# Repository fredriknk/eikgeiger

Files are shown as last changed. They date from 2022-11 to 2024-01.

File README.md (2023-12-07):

# EIKGEIGER
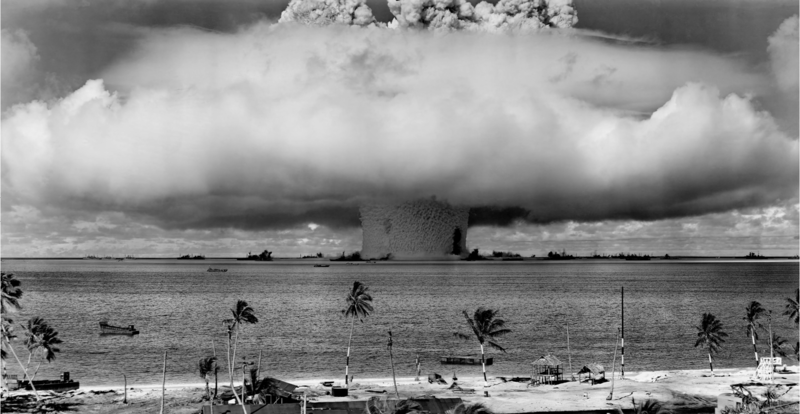
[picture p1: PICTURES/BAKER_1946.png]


Eikgeiger opensource project for detection of background radiation in Norway. It is developed in cooperation with Eik Ideverksted. Use the design for anything you like comercially and privately, but i would love if you fork it so i can see what it is used for.

## First Batch
Thanks to [PCBway](www.pcbway.com) for providing assembled prototype units for this project. Its awesome that you support the opensource community like this! If you want one for yourself, i've made a [pcbway project](https://www.pcbway.com/project/shareproject/EikGeiger_IOT_Geigercounter_60bd1e1f.html) which you can make an assembly order quite easily. 

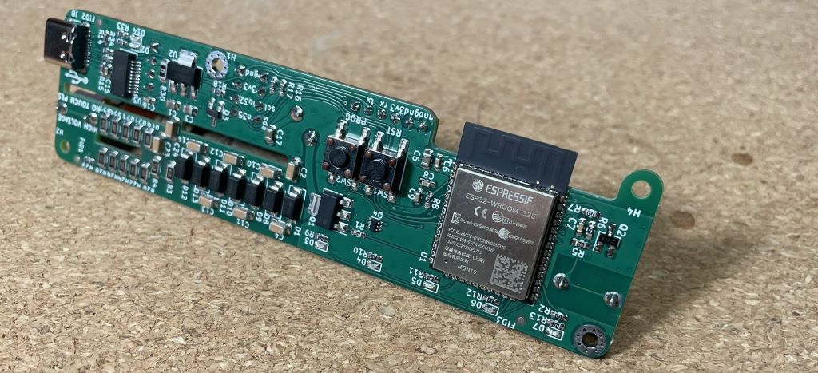
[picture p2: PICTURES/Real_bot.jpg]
REALBOT

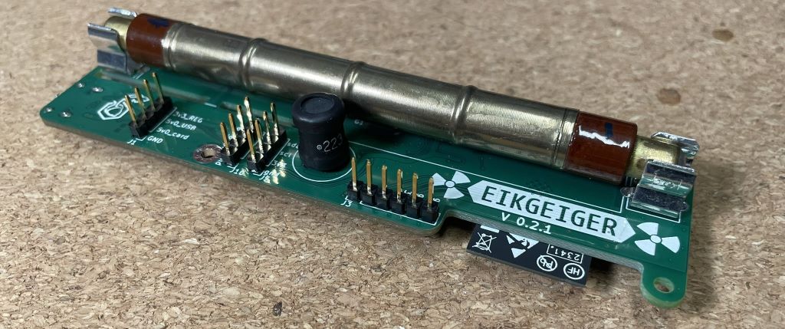
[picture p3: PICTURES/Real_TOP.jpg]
REALTOP


## Description
It uses an[ESP32-WROOM-32E](./DOCUMENTATION/esp32-wroom-32e_esp32-wroom-32ue_datasheet_en.pdf) wifi module both communication and MCU, and is mostly based on surface mount components.

Thanks to the DIYgeiger radmon project for inspiration [DIYGeiger RADMON + kit](https://sites.google.com/site/diygeigercounter/home/gk-radmon).

If you want to handsolder this, i really recommend to check out the awesome IBOM assembly utility (use it with a desktop as it sucks on mobile)
[Assembly IBOM](https://htmlpreview.github.io/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)

[SCHEMATIC](./DOCUMENTATION/Opengieger_schematic.pdf)
## Specifications
| **Parameter** | **Description** |
|---|---|
| _Input voltage_ | Usb-C cable, Header 4-6v, Direct 3.3v |
| _Current_ | Wifi: 150-250mA, Radio Off: 44mA, Only HV psup 4mA, Deep sleep 70uA |
| _Communication_ | 2.4ghz WIFI, Uart TTL, Uart over USB |
| _Baudrate_ | 115200 |
| _PCB size_ | 31x119mm |
| _Case size_ | 30x35x121mm |
| _Series Resistor_ | 4.51MOHM |

## Serial port controll comands

To reconfigure device settings you need to connect the eikgeiger to a computer with a serial terminal (I reccomend to just use the [Arduino Program](https://www.arduino.cc/en/software), but any serial terminal should work)

When you want to configure a value you use two characters plus a number. So to set the PWM frequency to 2000hz, you would write PF2000 in the terminal and send. Some commands need a specific number, eg to factory reset you must transmit FR9999. after you have verified that the configuraion works you use SA1 to save the config to the flash eeprom

| **Characters**| **Unit** | **Value** | **Factory Value** | **Description** | **Example** |
|---|---|---|---|---|---|
| VO | _VOLT (value/4096 %)_ | 0-2000 | 350 | Set pwm duty cycle, this is a value which controlls the duty cycle of HV power supply, it is a 12bit (4096) value, but you cant go over 50% or the coil field colapses. So keep it under 2046=50% duty cycle. (SBM-20 tubes like it best between 350-400) | VO350 |
| VF | _FREQUENCY (hz)_ | 0-18000 | 1001 | Set pwm frequency, from experimentation i have found ~1000hz to be most effective but it can make some coil whine, It is smart to not have this as a value divisible by log output, or it might generate some interferance with ADC readings | VF1001 |
| SA | _SAVE_ | 1 | - | Saves parameters to eeprom | SA1 |
| RE | _RESTART_ | 1 | - | Restarts device | RE1 |
| RF | _FACTORY RESET_ | 9999/1111 | - | Resets all values to factory default and restarts device, 1111 will reset all settings except wifi and radmon credentials, 9999 resets everything | RF9999 |
| BE | _BEEPER (activation)_ | 0/1 | 0 | Activate beeper output 0=Off 1=On | BE1 |
| BD | _BEEPER duty (val/255) _| 0-127 | 50 | Beeper duty cycle, higher number is louder | BD50 |
| BF | _BEEPER FREQUENCY (hz)_ | 10-40000  | 6000 | Beeper frequency 6000hZ is a very nice and annoying frequency | BF6000 |
| LE | _LED (activation)_ | 0/1 | 1 | Activate LED output 0=Off 1=On | LE1 |
| LF | _FLASHTIME (mS)_ | 1-500 | 10 | How long the beeper beeps and led flashes in mS for every click. If value is higher than 60*1000/CPM, you will have counts without indication | LF10 |
| LO | _LOG OUTPUT_ | 0/1 | 1 | Outputs  raw_volt:(Voltage ADC reading, arbtrary number not directly related to volt) set_volt:(Duty cycle value) cpmM:(Running average CPM for one minute) cpmH:(Running average CPM for one hour) cpm:(CPM value for last detection) | LO1 |
| LS | _LOG SPEED_ | 0-10000 | 1000 | Number of milliseconds for every log output over serial 																																							 | LS1000 |
| EV | _EVENTS (number)_ | 0-1000 | 0 | How many events for one flash, in practice it will divide by that number, so a value of 10, it will need 10 detections for every led and ticker flash. | EV0 |

## Description
The pcb has one pinheader (J5) which can be used for 1 x i2c or 2 x Onewire io,
and one header (J10) with 1xGpio, and 1x mosfet open collector for eg a clicker.
A piezo buzzer with 5mm pitch can be directly soldered in the header holes.
It is allso possible to split out the 5v from the usb to insert an ebay generic lipo charger/powersuply to make it battery driven with usb charging.

It allso implements an integrated FTDI chip to get serial over USB, 
and a transistor based rts#/dtr# pulldown function for the boot pin on the ESP 
(shamelessly stolen from the weemos d1 mini design) 
so it allows for automatic programming over USB without pushing the boot pin.

## Homeassistant Implementation
To add the sensor in home assistant, use the following YAML sensor, supplied by u/[chillinorway](https://github.com/chillinorway)
```
sensor:
  - platform: rest
    name: EIK_Geiger
    resource: http://<IP-Address>/cpm
    json_attributes:
      - "data"
    value_template: "OK"
  - platform: template
    sensors:
      cpm:
        value_template: "{{ state_attr('sensor.EIK_Geiger', 'data')['cpm'] }}"
        unit_of_measurement: "cpm"
      cpm_m:
        value_template: "{{ state_attr('sensor.EIK_Geiger', 'data')['cpm_M'] }}"
        unit_of_measurement: "cpm_avg_m"
      cpm_h:
        value_template: "{{ state_attr('sensor.EIK_Geiger', 'data')['cpm_H'] }}"
        unit_of_measurement: "cpm_avg_h"
      raw_volt:
        value_template: "{{ state_attr('sensor.EIK_Geiger', 'data')['raw_volt'] }}"
        unit_of_measurement: "raw_voltage"
```
## BUCK BOOST CONVERTER
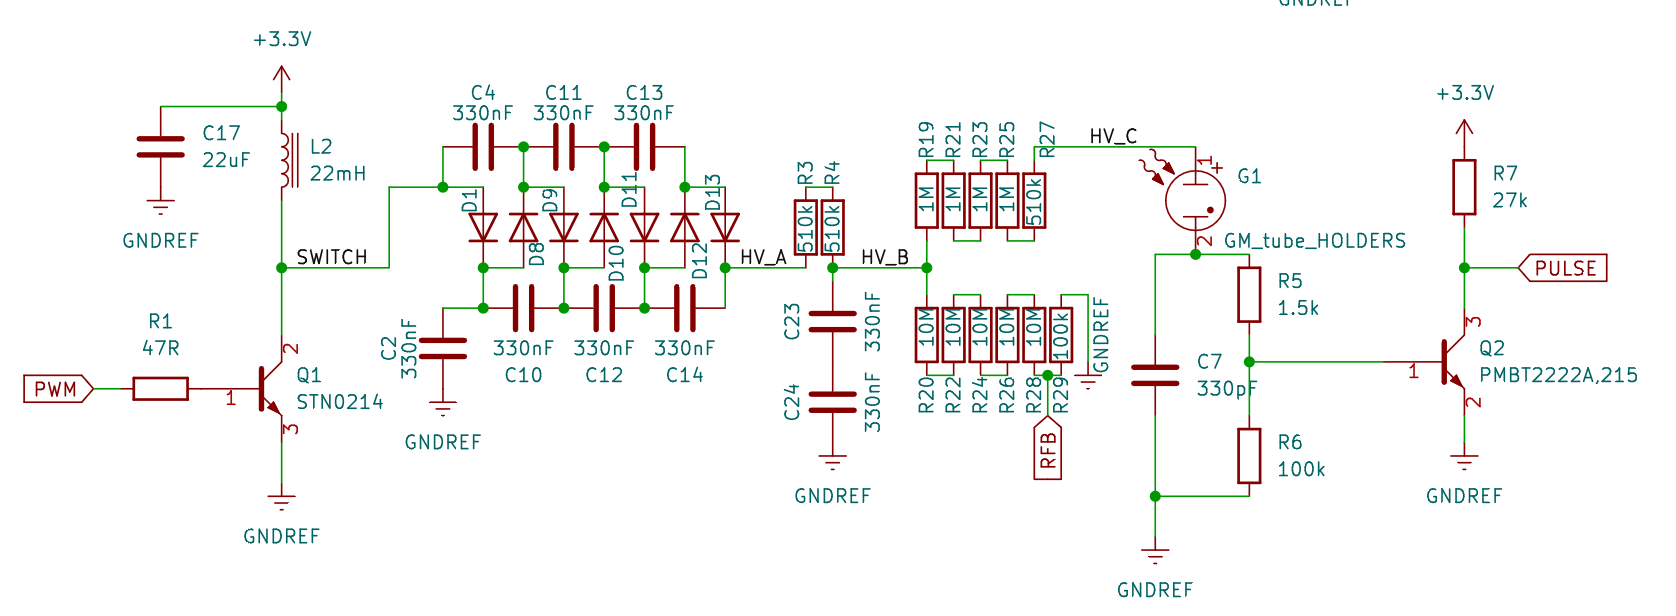
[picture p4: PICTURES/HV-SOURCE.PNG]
HV SOURCE


It is designed for SBM-20 GM tube integrated onto the PCB with 6.3mm fuse holders, but it can use any tube up to 1000v if you just solder on some leads. The power supply is a standard buck boost, but with a 4x voltage multiplier output. It seems reaonably of effective, and consumes about 4ma@3.3v delivering 350v out running at 1000hz pwm. It has a voltage feedback read by adc2 on the esp32 module, but from experimentation i found it more stable to just set a pwm level rather than actively regulating it

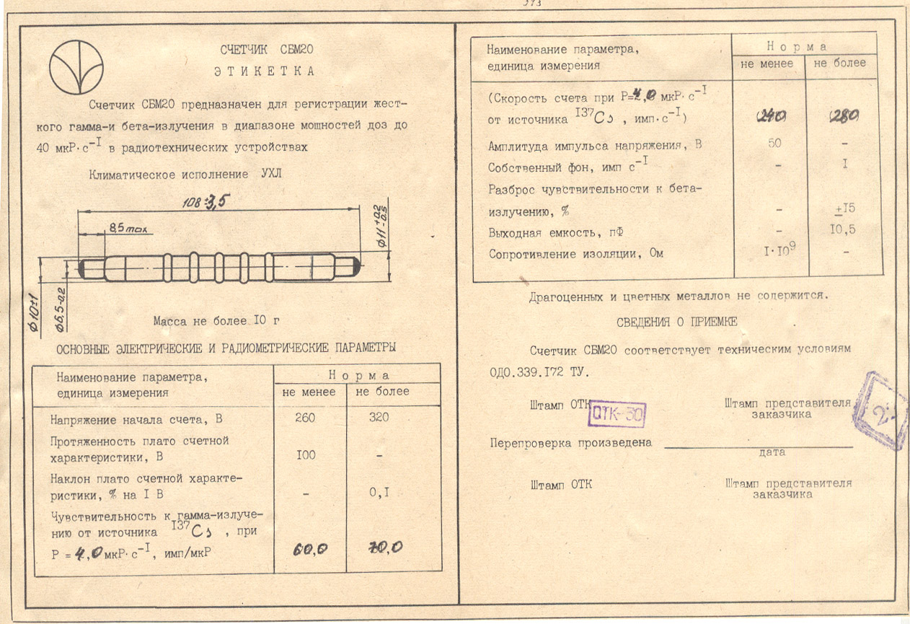
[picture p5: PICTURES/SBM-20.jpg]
SBM DATASHEET


## More Pictures
### Renders

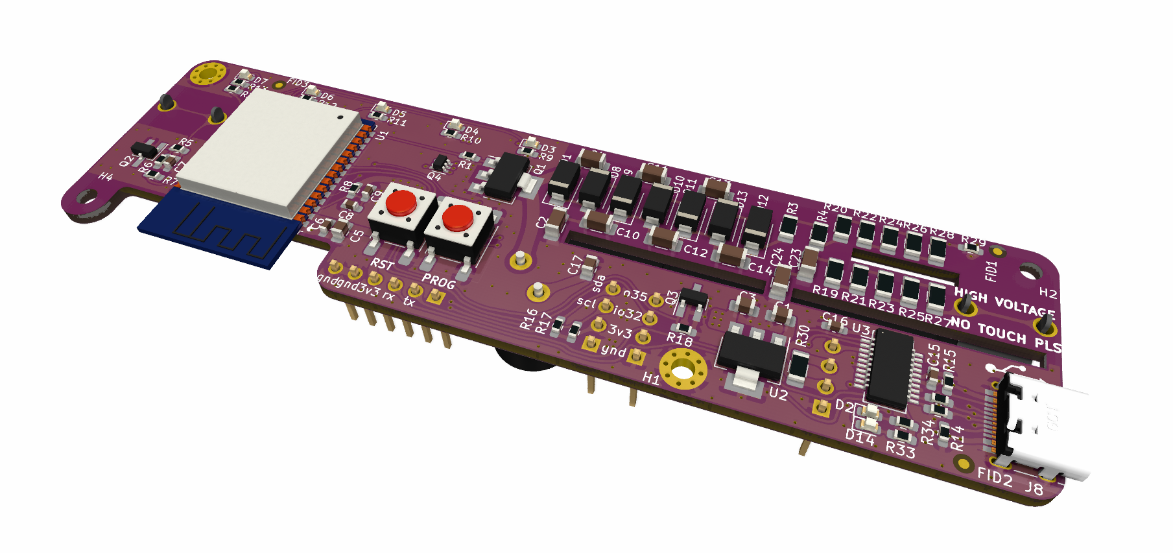
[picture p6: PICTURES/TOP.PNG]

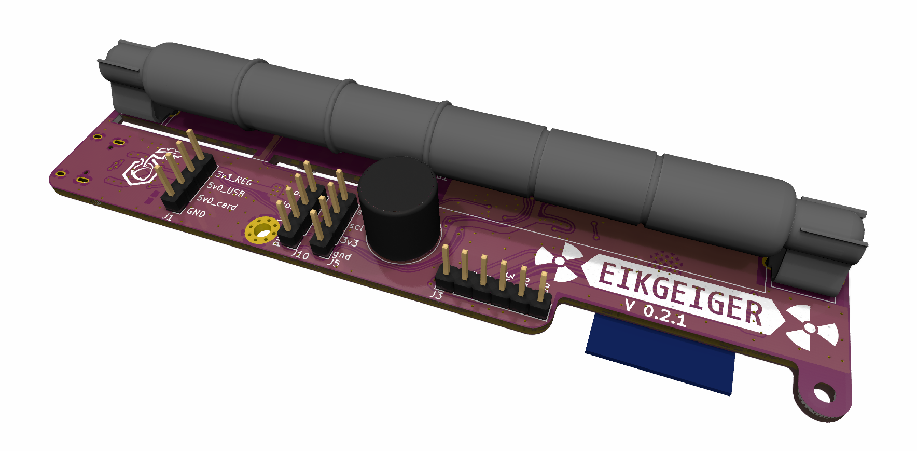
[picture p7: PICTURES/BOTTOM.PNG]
Back


### SBM-20 Enclosure
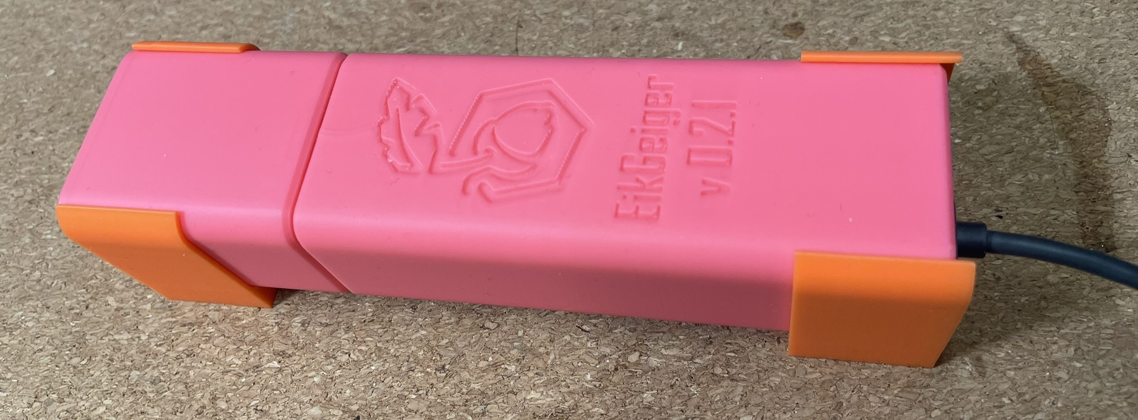
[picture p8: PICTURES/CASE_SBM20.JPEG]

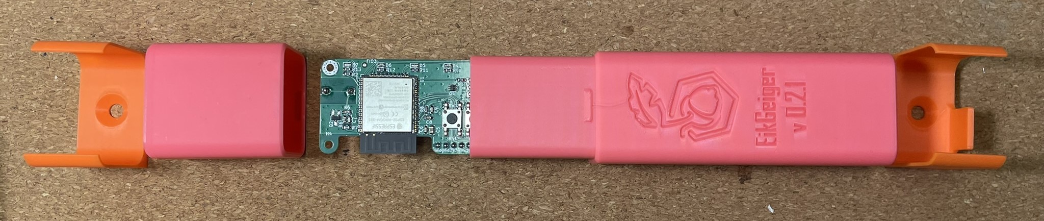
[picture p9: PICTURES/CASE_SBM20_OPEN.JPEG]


### SBM-19 Enclosure
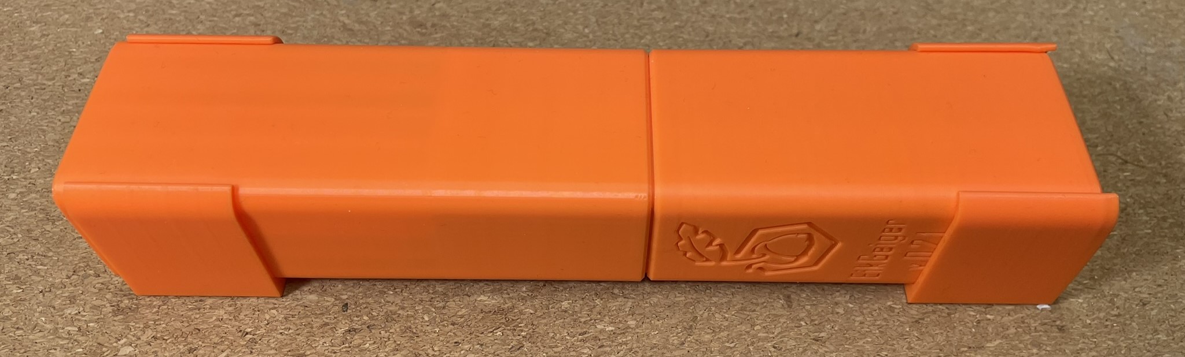
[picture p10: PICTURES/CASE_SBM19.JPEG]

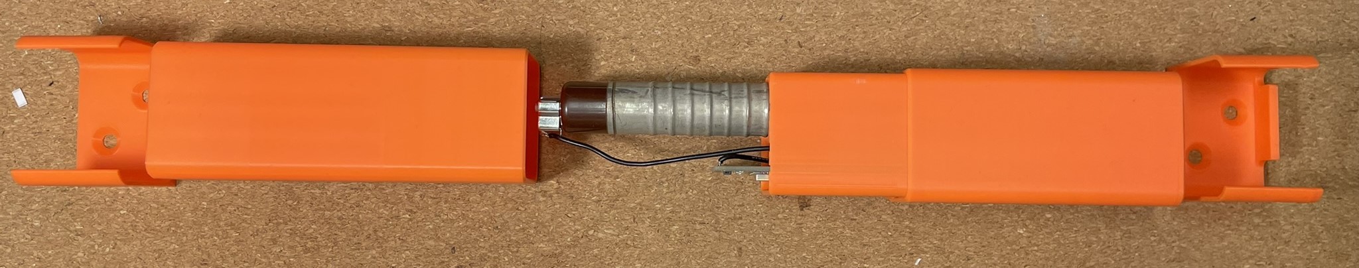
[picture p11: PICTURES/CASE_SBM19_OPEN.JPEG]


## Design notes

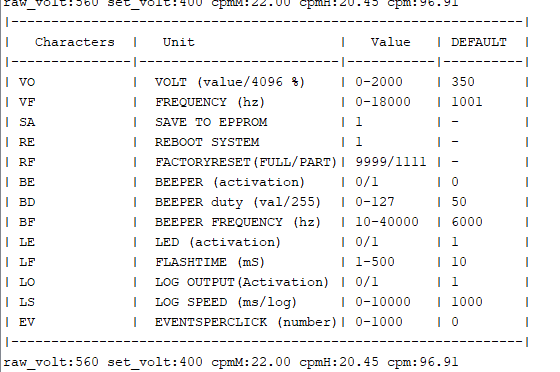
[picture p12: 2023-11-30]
PICTURES/Help.PNG

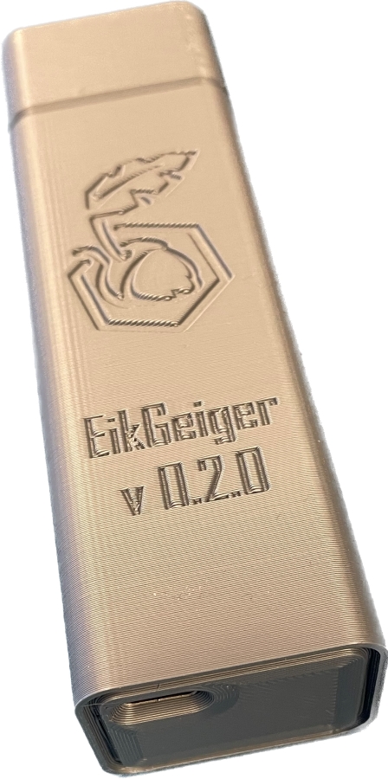
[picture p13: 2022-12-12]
PICTURES/CASE_900px.jpeg

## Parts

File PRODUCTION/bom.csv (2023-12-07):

Designator | Footprint | Quantity | Value | LCSC Part #
C1, C17, C3, C5 | 0805 | 4 | 22uF | C398815
C10, C11, C12, C13, C14, C2, C23, C24, C4 | 1206 | 9 | 330nF | C710477
C15, C16, C6, C8, C9 | 0603 | 5 | 0.1uF | C14663
C7 | 0603 | 1 | 330pF | C1664
D1, D10, D11, D12, D13, D8, D9 | D_SMA | 7 | RS1J | C434030
D14, D2, D3, D4, D5, D6, D7 | 0603 | 7 | RED_LED | C2286
F1, F2 | FC-102-22 | 2 | 6.35mm Fuse holder | C3206833
FID1, FID2, FID3 | Fiducial_1mm_Mask2mm | 3 | Fiducial
G1 | SBM-20 | 1 | GM_tube_HOLDERS
H1, H3 | MountingHole_2.5mm_Pad_Via | 2 | MountingHole_Pad
H2, H4 | MountingHole_2.5mm | 2 | MountingHole_Pad
J1, J10, J5 | PinHeader_1x04_P2.54mm_Vertical | 3 | Conn_01x04 | C2691448
J3 | PinHeader_1x06_P2.54mm_Vertical | 1 | Conn_01x06 | C37208
J8 | USB_C_Receptacle_HRO_TYPE-C-31-M-12 | 1 | USB_C_Receptacle_USB2.0 | C2765186
L2 | L_Radial_D10.5mm_P5.00mm_Abacron_AISR-01 | 1 | 22mH | C1330068
Q1 | SOT-223 | 1 | STN0214 | C2969811
Q2 | SOT-23_Handsoldering | 1 | PMBT2222A,215 | C23869
Q3 | SOT-23_Handsoldering | 1 | DMG2302UK-7 | C460977
Q4 | SOT-363_SC-70-6 | 1 | UMH3N | C62892
R1, R31, R32 | 0603 | 3 | 47R | C23182
R10, R11, R12, R13, R33, R34, R9 | 0603 | 7 | 270R | C22966
R14, R15 | 0603 | 2 | 5.1k | C23186
R16, R17, R18, R2, R8 | 0603 | 5 | 10k | C25804
R19, R21, R23, R25 | 1206 | 4 | 1M | C253347
R20, R22, R24, R26, R28 | 1206 | 5 | 10M | C2075848
R27, R3, R4 | 1206 | 3 | 510k | C17990
R29, R6 | 0603 | 2 | 100k | C25803
R30 | 1206 | 1 | 0R | C17888
R5 | 0603 | 1 | 1.5k | C22843
R7 | 0603 | 1 | 27k | C22967
SW1, SW2 | SW_TL3301NF160QG_TR | 2 | TL3301NF160QG/TR | C255812
U1 | ESP32-WROOM-32 | 1 | ESP32-WROOM-32E | C701343
U2 | SOT-223-3_TabPin2 | 1 | TC1264-3.3VDBTR | C6186
U3 | SSOP-20_3.9x8.7mm_P0.635mm | 1 | FT231XS | C132160

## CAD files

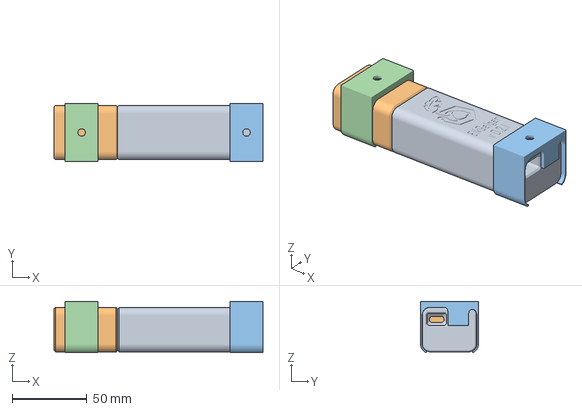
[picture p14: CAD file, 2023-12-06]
3D_MODEL/ENCLOSURE/Enclosure_SBM20 v3.3mf
139.5 x 38.8 x 34.3 mm

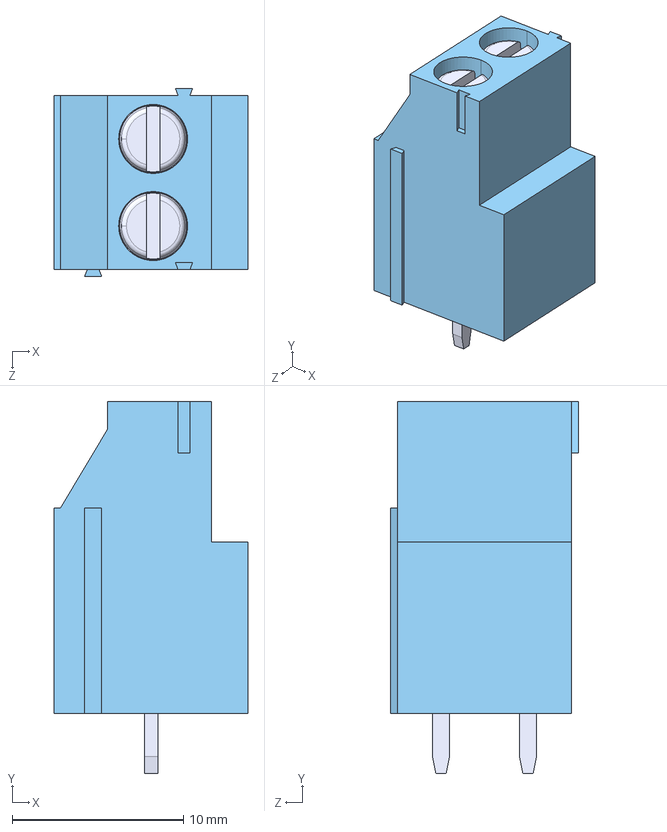
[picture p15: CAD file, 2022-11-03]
CAD/Models/CUI_DEVICES_TB010-508-02BE.step
11.3 x 21.7 x 11.0 mm

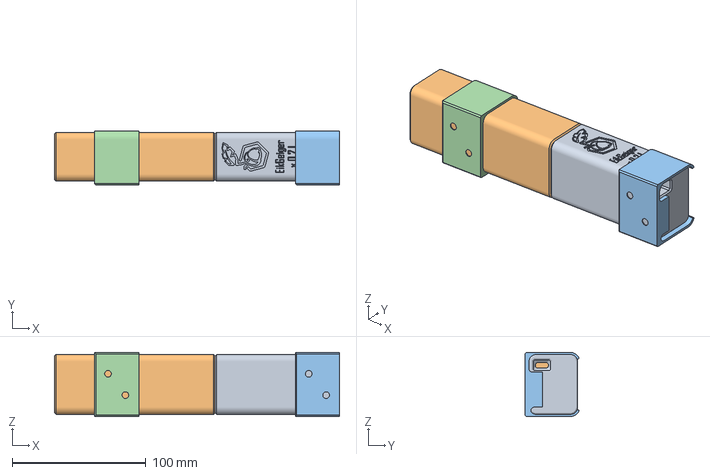
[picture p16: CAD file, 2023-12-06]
3D_MODEL/ENCLOSURE/Enclosure_SBM19 v15.3mf
213.0 x 40.4 x 47.9 mm

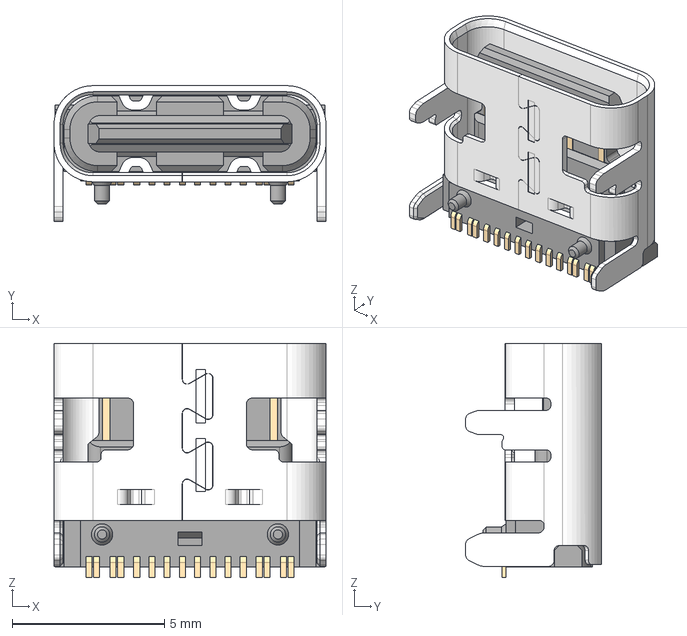
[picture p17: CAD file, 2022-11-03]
CAD/Models/USB4105-15-A-120.stp
8.94 x 4.46 x 7.70 mm
USB4105-15-A-120_PART2
USB4105-15-A-120_PART1

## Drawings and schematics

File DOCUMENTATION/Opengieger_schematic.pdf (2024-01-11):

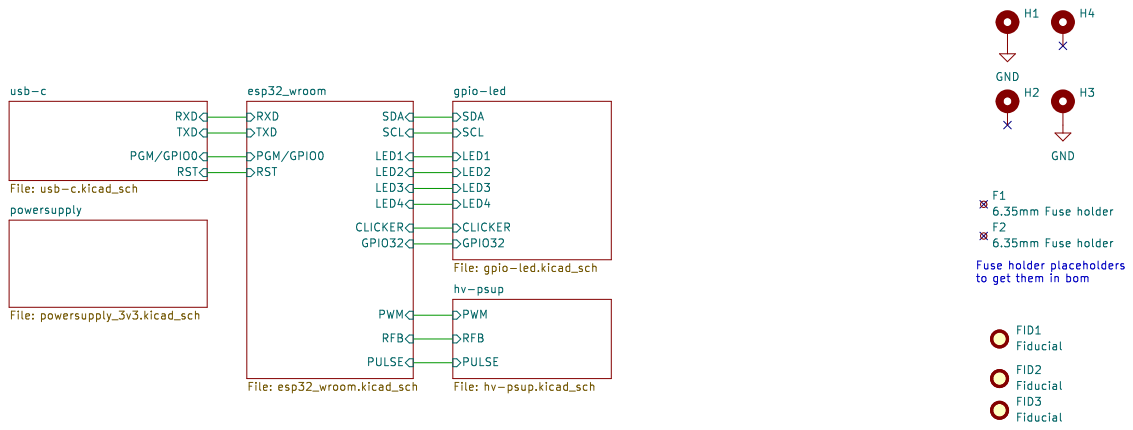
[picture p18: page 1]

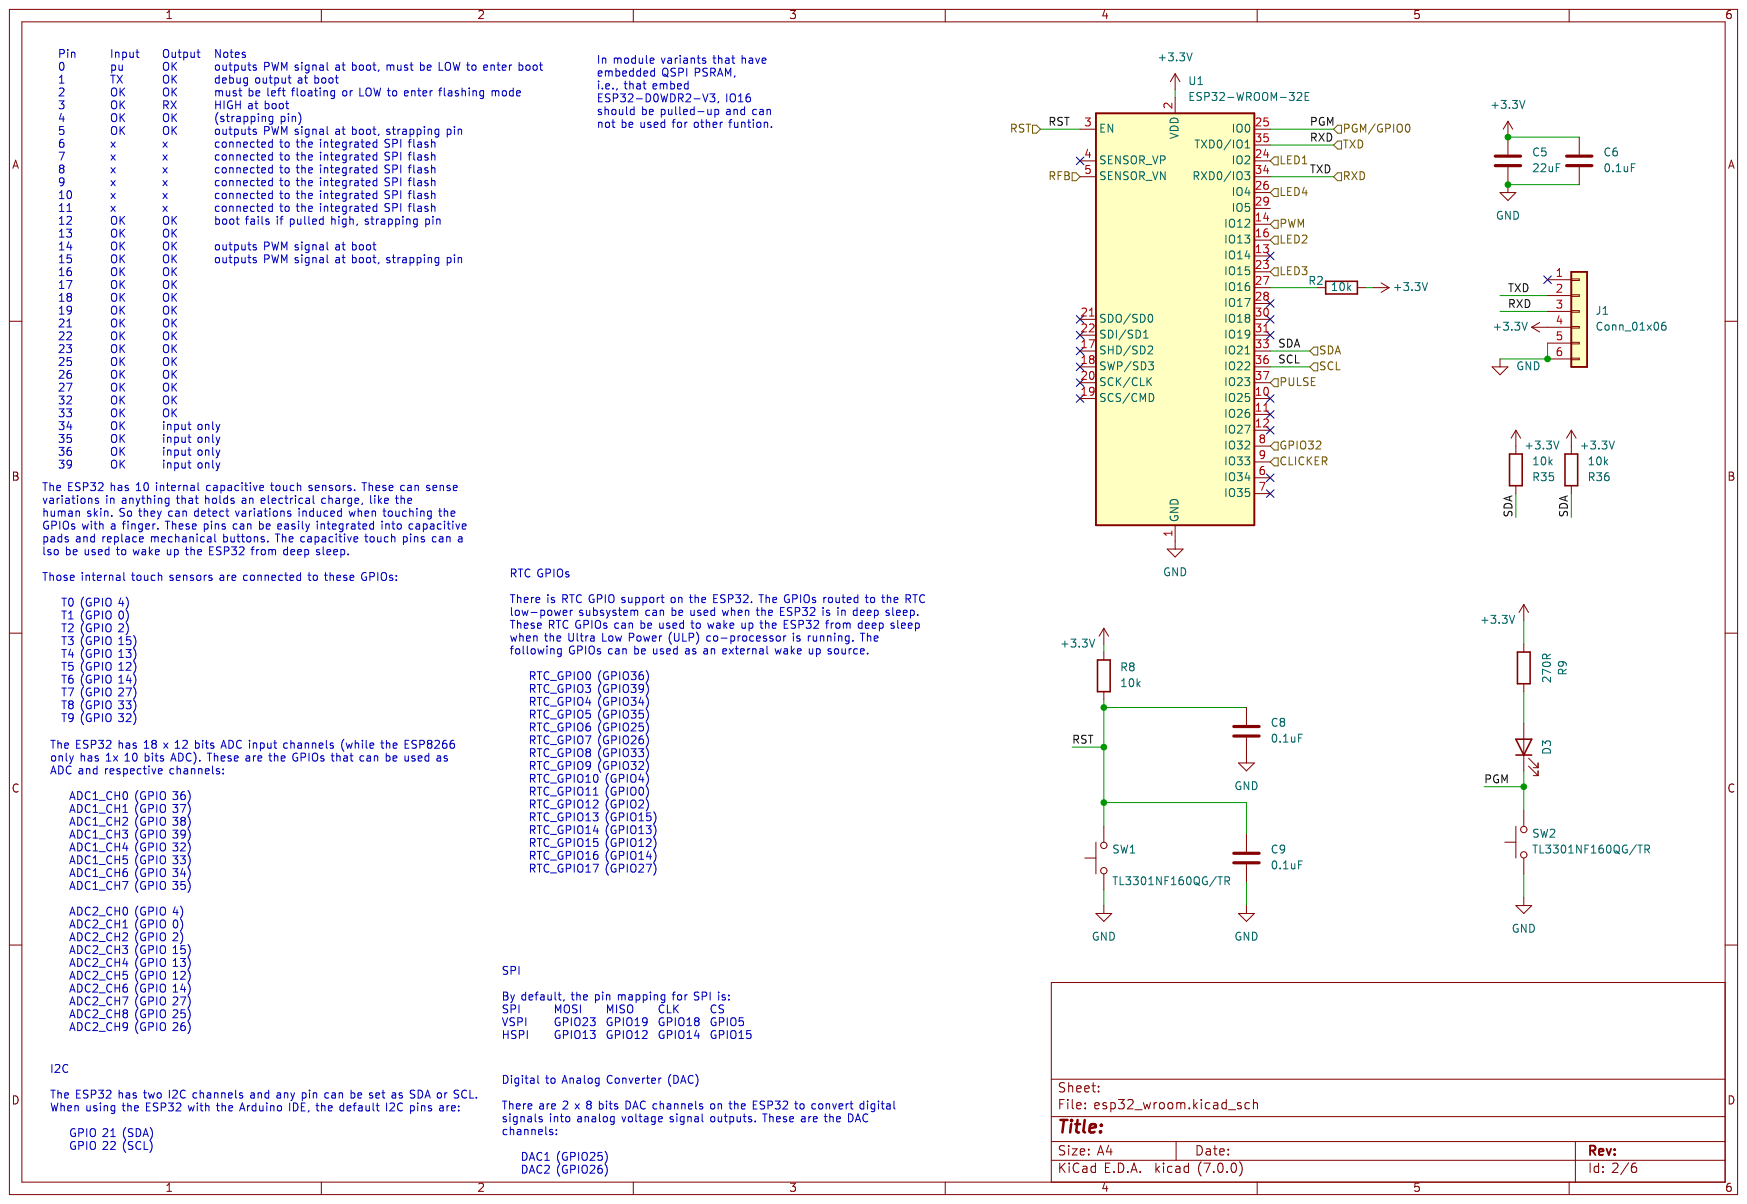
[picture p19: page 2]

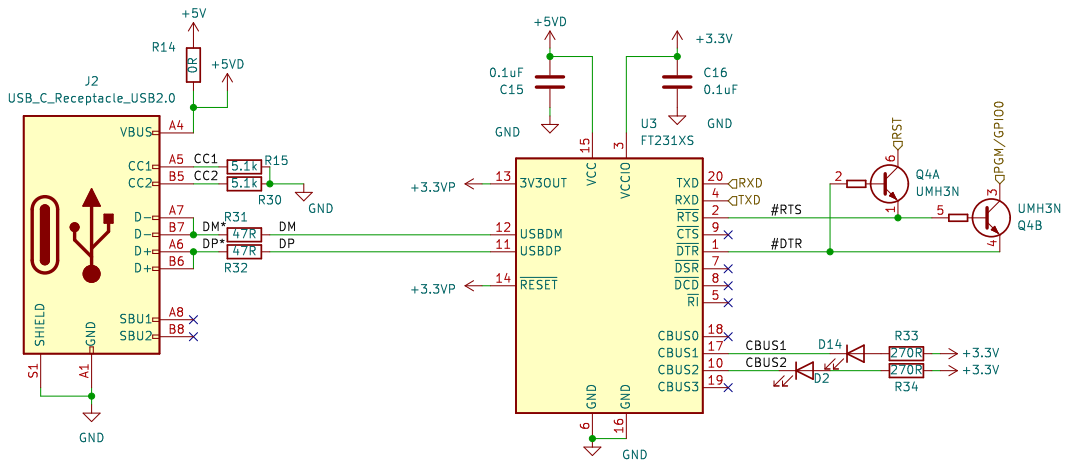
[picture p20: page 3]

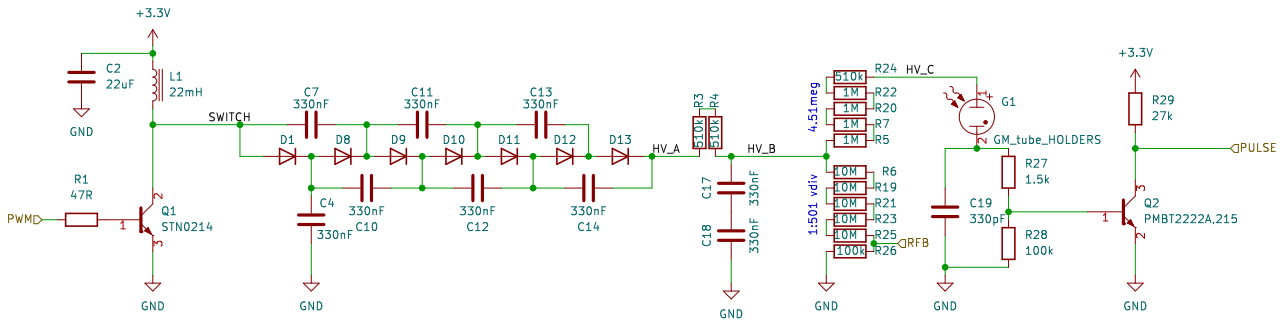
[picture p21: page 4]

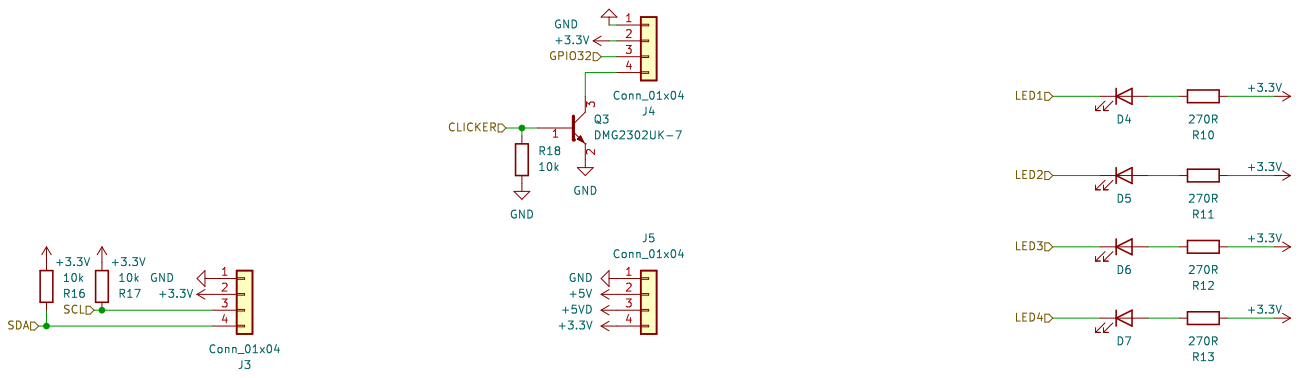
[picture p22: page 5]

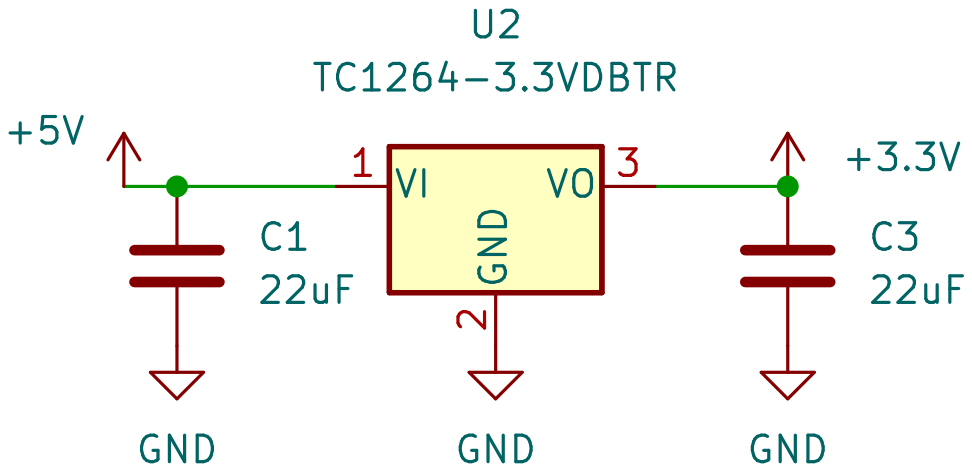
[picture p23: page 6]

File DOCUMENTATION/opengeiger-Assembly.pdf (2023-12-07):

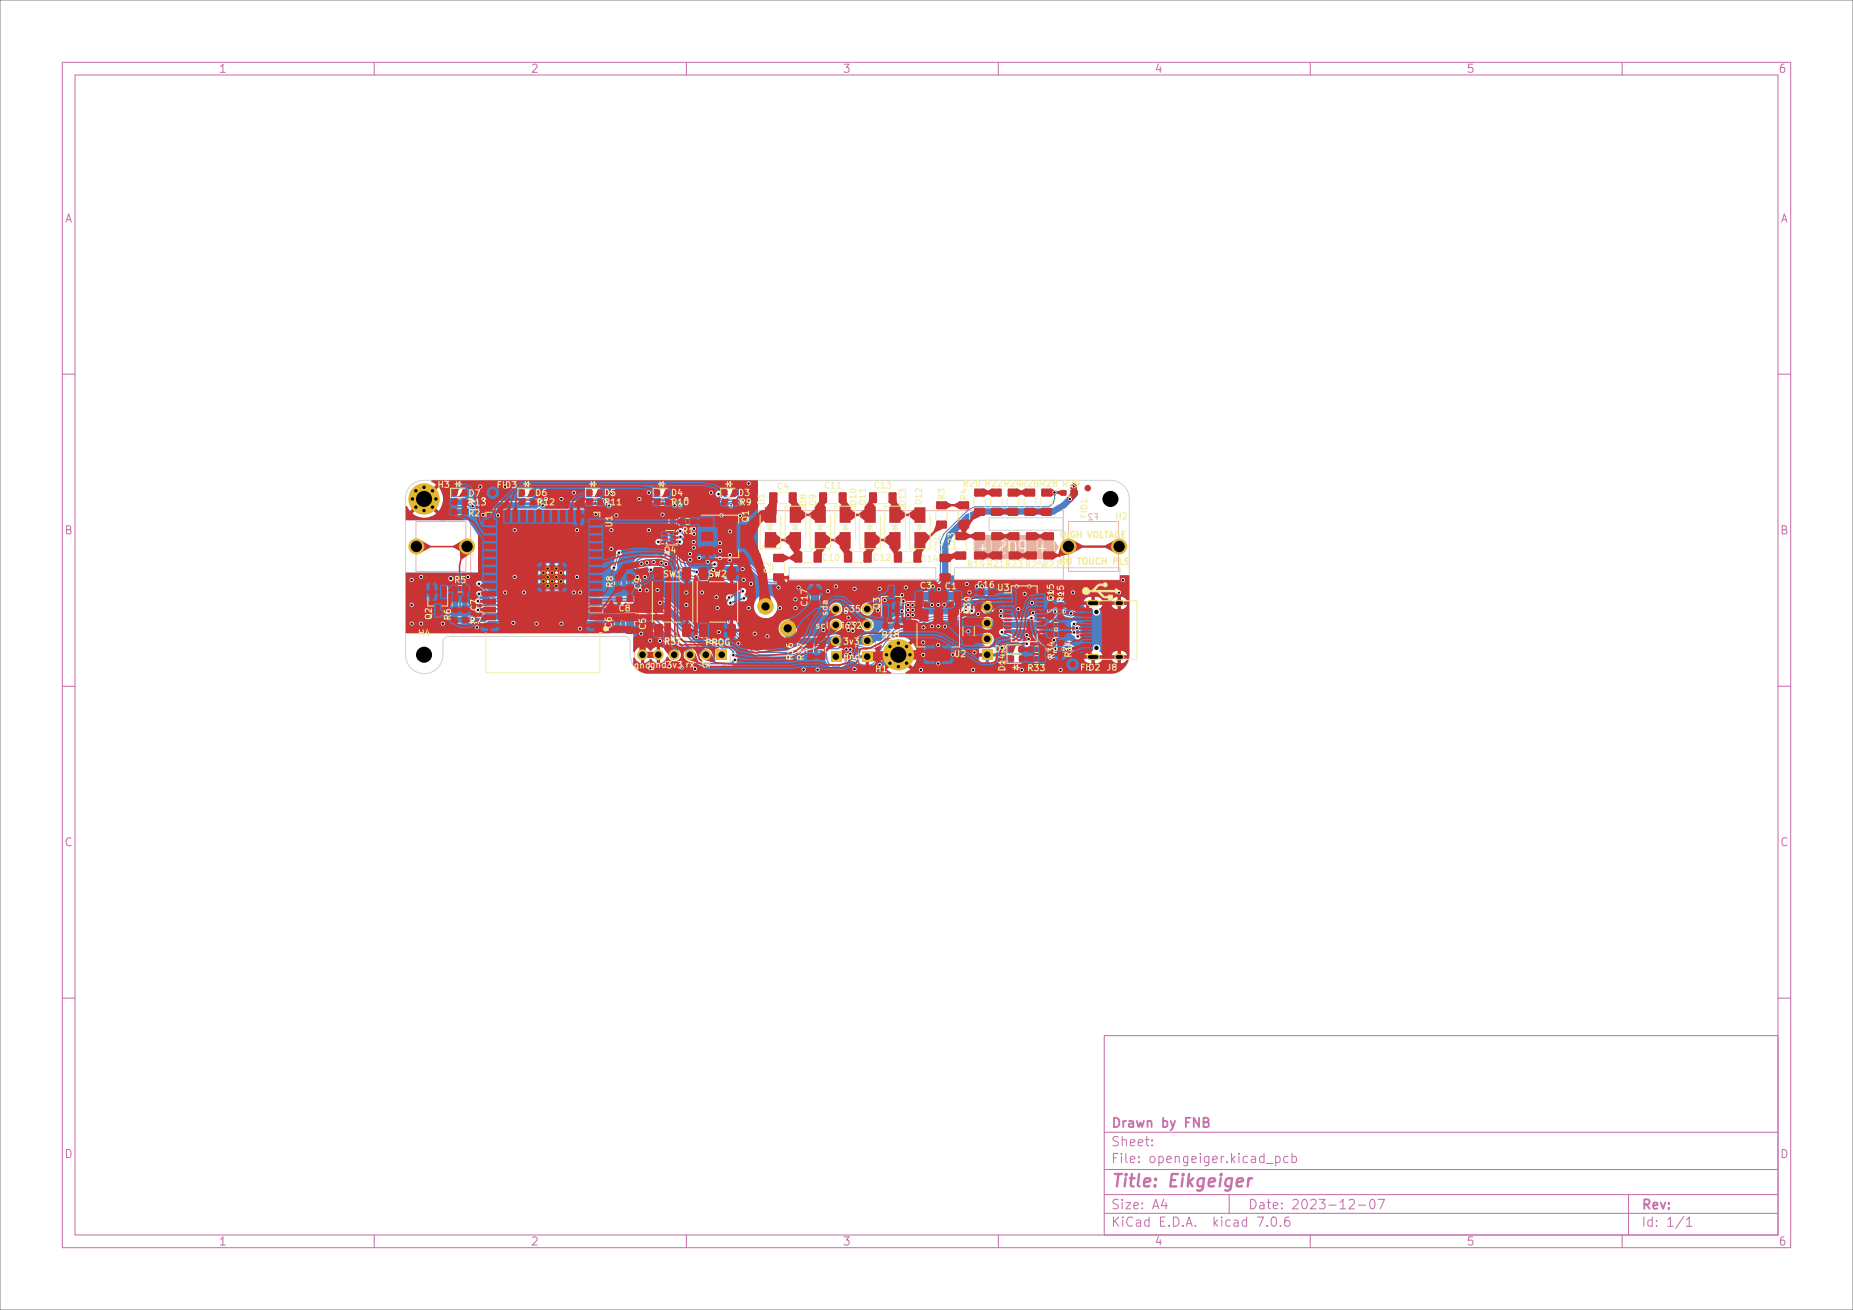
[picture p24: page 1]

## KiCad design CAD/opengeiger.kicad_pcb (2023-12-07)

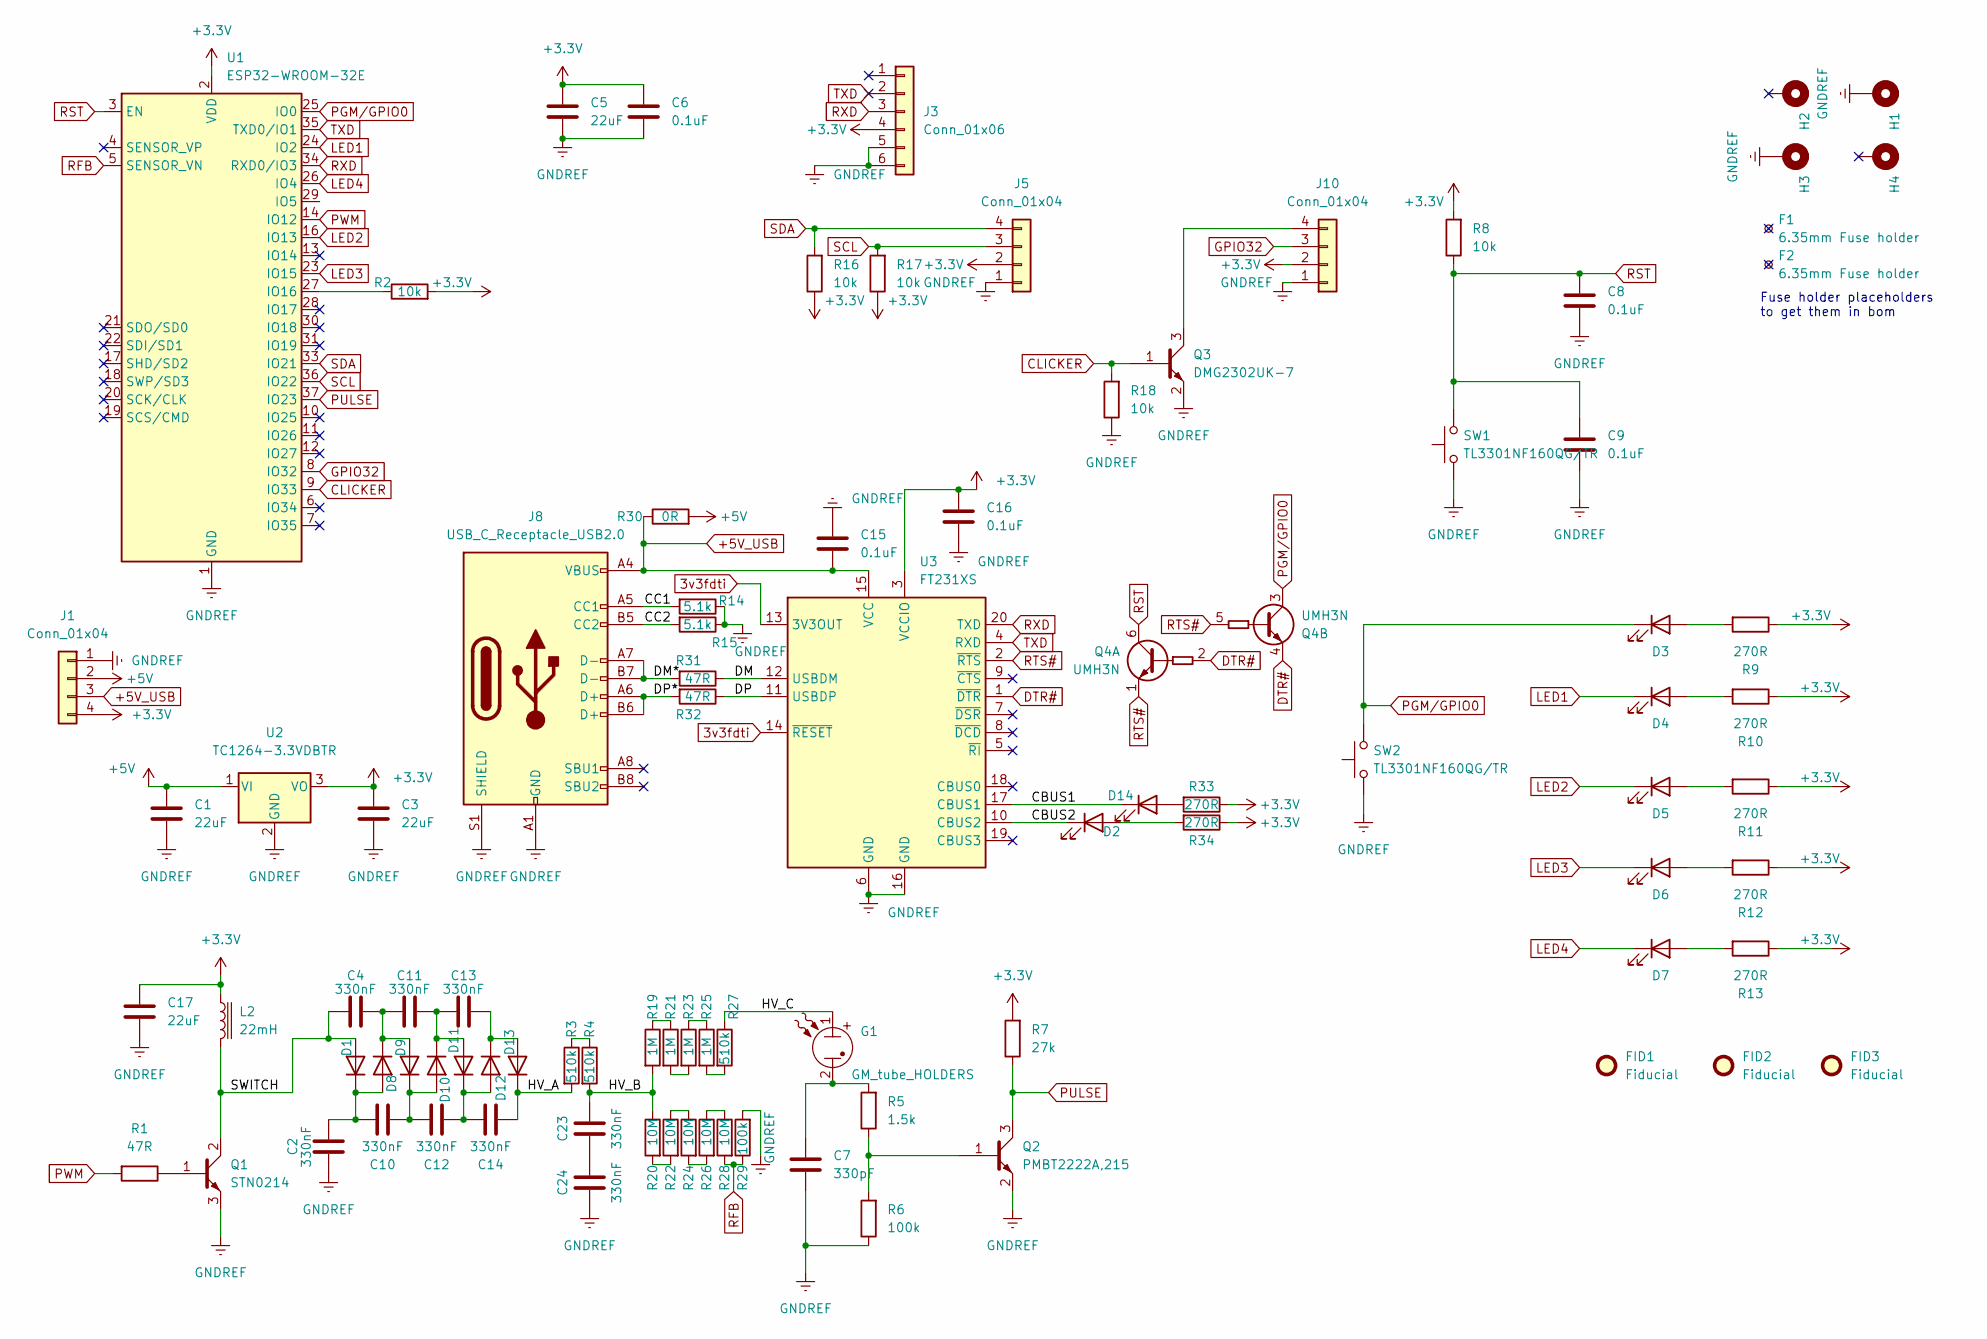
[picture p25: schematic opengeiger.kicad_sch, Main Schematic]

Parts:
C1, C3, C5, C17: 22uF; C_0805_2012Metric_Pad1.18x1.45mm_HandSolder; MPN CL21A226MOCLRNC; LCSC Part # C398815
C2, C4, C10, C11, C12, C13, C14, C23, C24: 330nF; C_1206_3216Metric_Pad1.33x1.80mm_HandSolder; MPN CL31B333KHHSFNE; LCSC Part # C710477
C6, C8, C9, C15, C16: 0.1uF; C_0603_1608Metric_Pad1.08x0.95mm_HandSolder; MPN CC0603KRX7R9BB104; LCSC Part # C14663
C7: 330pF; C_0603_1608Metric_Pad1.08x0.95mm_HandSolder; MPN CL10C331JB8NNNC; LCSC Part # C1664
D1, D8, D9, D10, D11, D12, D13: RS1J; D_SMA; MPN RS1J; LCSC Part # C434030
D2, D3, D4, D5, D6, D7, D14: RED_LED; LED_0603_1608Metric; MPN LTST-C191KRKT; LCSC Part # C2286
F1, F2: 6.35mm Fuse holder; FC-102-22; MPN FC-102 BRIGHT TIN; LCSC Part # C3206833
FID1, FID2, FID3: Fiducial; Fiducial_1mm_Mask2mm
G1: GM_tube_HOLDERS; SBM-20; MPN SBM-20
H1, H3: MountingHole_Pad; MountingHole_2.5mm_Pad_Via
H2, H4: MountingHole_Pad; MountingHole_2.5mm
J1, J5, J10: Conn_01x04; PinHeader_1x04_P2.54mm_Vertical; MPN 61300411121; LCSC Part # C2691448
J3: Conn_01x06; PinHeader_1x06_P2.54mm_Vertical; MPN 61300611121; LCSC Part # C37208
J8: USB_C_Receptacle_USB2.0; USB_C_Receptacle_HRO_TYPE-C-31-M-12; MPN CONN RCP USB2.0 TYP C 24P SMD RA; LCSC Part # C2765186
L2: 22mH; L_Radial_D10.5mm_P5.00mm_Abacron_AISR-01; MPN RLB1014-223KL; LCSC Part # C1330068
Q1: STN0214; SOT-223; MPN STN0214; LCSC Part # C2969811
Q2: PMBT2222A,215; SOT-23_Handsoldering; MPN PMBT2222A,215; LCSC Part # C23869
Q3: DMG2302UK-7; SOT-23_Handsoldering; MPN DMG2302UK-7; LCSC Part # C460977
Q4: UMH3N; SOT-363_SC-70-6; MPN UMH3N; LCSC Part # C62892
R1, R31, R32: 47R; R_0603_1608Metric_Pad0.98x0.95mm_HandSolder; MPN RMCF0603JT47R0; LCSC Part # C23182
R2, R8, R16, R17, R18: 10k; R_0603_1608Metric_Pad0.98x0.95mm_HandSolder; MPN RMCF0603JT10K0; LCSC Part # C25804
R3, R4, R27: 510k; R_1206_3216Metric_Pad1.30x1.75mm_HandSolder; MPN KTR18EZPJ514; LCSC Part # C17990
R5: 1.5k; R_0603_1608Metric_Pad0.98x0.95mm_HandSolder; MPN RNCP0603FTD1K50; LCSC Part # C22843
R6, R29: 100k; R_0603_1608Metric_Pad0.98x0.95mm_HandSolder; MPN RMCF0603JT100K; LCSC Part # C25803
R7: 27k; R_0603_1608Metric_Pad0.98x0.95mm_HandSolder; MPN RMCF0603JT27K0; LCSC Part # C22967
R9, R10, R11, R12, R13, R33, R34: 270R; R_0603_1608Metric_Pad0.98x0.95mm_HandSolder; MPN RC0603JR-07270RL; LCSC Part # C22966
R14, R15: 5.1k; R_0603_1608Metric_Pad0.98x0.95mm_HandSolder; MPN RMCF0603JT5K10; LCSC Part # C23186
R19, R21, R23, R25: 1M; R_1206_3216Metric_Pad1.30x1.75mm_HandSolder; MPN KTR18EZPF1004; LCSC Part # C253347
R20, R22, R24, R26, R28: 10M; R_1206_3216Metric_Pad1.30x1.75mm_HandSolder; MPN KTR18EZPF1005; LCSC Part # C2075848
R30: 0R; R_1206_3216Metric_Pad1.30x1.75mm_HandSolder; MPN KTR18EZPF0; LCSC Part # C17888
SW1, SW2: TL3301NF160QG/TR; SW_TL3301NF160QG_TR; MPN TL3301NF160QG/TR; LCSC Part # C255812
U1: ESP32-WROOM-32E; ESP32-WROOM-32; MPN ESP32-WROOM-32E-N16; LCSC Part # C701343
U2: TC1264-3.3VDBTR; SOT-223-3_TabPin2; MPN TC1264-3.3VDBTR; LCSC Part # C6186
U3: FT231XS; SSOP-20_3.9x8.7mm_P0.635mm; MPN FT231XS; LCSC Part # C132160

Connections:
3v3fdti: U3.13 (3V3OUT), U3.14 (~RESET)
+3.3V: C3.1, C5.1, C6.1, C16.1, C17.1, J1.4, J3.4, J5.2, J10.2, L2.1, R2.2, R7.2, R8.2, R9.1, R10.1, R11.1, R12.1, R13.1, R16.1, R17.1, R33.1, R34.1, U1.2 (VDD), U2.3 (VO), U3.3 (VCCIO)
+5V: C1.1, J1.2, R30.2, U2.1 (VI)
+5V_USB: C15.2, J1.3, J8.A4 (VBUS), J8.A9 (VBUS), J8.B4 (VBUS), J8.B9 (VBUS), R30.1, U3.15 (VCC)
/CBUS1: D14.1 (K), U3.17 (CBUS1)
/CBUS2: D2.1 (K), U3.10 (CBUS2)
/CC1: J8.A5 (CC1), R14.2
/CC2: J8.B5 (CC2), R15.2
/DM: R31.1, U3.12 (USBDM)
/DM*: J8.A7 (D-), J8.B7 (D-), R31.2
/DP: R32.1, U3.11 (USBDP)
/DP*: J8.A6 (D+), J8.B6 (D+), R32.2
/HV_A: C14.2, D13.1 (K), R3.2
/HV_B: C23.2, R4.2, R19.2, R20.1
/HV_C: G1.1, R27.1
/SWITCH: C4.1, D1.2 (A), L2.2, Q1.2 (C), Q1.4 (C)
CLICKER: Q3.1 (B), R18.2, U1.9 (IO33)
DTR#: Q4.2 (B1), Q4.4 (E2), U3.1 (~DTR)
GNDREF: C1.2, C2.1, C3.2, C5.2, C6.2, C7.2, C8.2, C9.2, C15.1, C16.2, C17.2, C24.1, H1.1, H3.1, J1.1, J3.5, J3.6, J5.1, J8.A1 (GND), J8.A12 (GND), J8.B1 (GND), J8.B12 (GND), J8.S1 (SHIELD), J10.1, Q1.3 (E), Q2.2 (E), Q3.2 (E), R6.1, R14.1, R15.1, R18.1, R29.2, SW1.1, SW2.1, U1.1 (GND), U1.15 (GND), U1.38 (GND), U1.39 (GND), U2.2 (GND), U3.6 (GND), U3.16 (GND)
GPIO32: J10.3, U1.8 (IO32)
LED1: D4.1 (K), U1.24 (IO2)
LED2: D5.1 (K), U1.16 (IO13)
LED3: D6.1 (K), U1.23 (IO15)
LED4: D7.1 (K), U1.26 (IO4)
unnamed: C7.1, G1.2, R5.2
unnamed: C23.1, C24.2
unnamed: C2.2, C10.1, D1.1 (K), D8.2 (A)
unnamed: D2.2 (A), R34.2
unnamed: D3.2 (A), R9.2
unnamed: D4.2 (A), R10.2
unnamed: D5.2 (A), R11.2
unnamed: D6.2 (A), R12.2
unnamed: D7.2 (A), R13.2
unnamed: C4.2, C11.1, D8.1 (K), D9.2 (A)
unnamed: C10.2, C12.1, D9.1 (K), D10.2 (A)
unnamed: C11.2, C13.1, D10.1 (K), D11.2 (A)
unnamed: C12.2, C14.1, D11.1 (K), D12.2 (A)
unnamed: C13.2, D12.1 (K), D13.2 (A)
unnamed: D14.2 (A), R33.2
unnamed: J10.4, Q3.3 (C)
unnamed: Q1.1 (B), R1.1
unnamed: Q2.1 (B), R5.1, R6.2
unnamed: R3.1, R4.1
unnamed: R19.1, R21.1
unnamed: R20.2, R22.2
unnamed: R21.2, R23.2
unnamed: R22.1, R24.1
unnamed: R23.1, R25.1
unnamed: R24.2, R26.2
unnamed: R25.2, R27.2
unnamed: R26.1, R28.1
unnamed: R2.1, U1.27 (IO16)
PGM/GPIO0: D3.1 (K), Q4.3 (C2), SW2.2, U1.25 (IO0)
PULSE: Q2.3 (C), R7.1, U1.37 (IO23)
PWM: R1.2, U1.14 (IO12)
RFB: R28.2, R29.1, U1.5 (SENSOR_VN)
RST: C8.1, C9.1, Q4.6 (C1), R8.1, SW1.2, U1.3 (EN)
RTS#: Q4.1 (E1), Q4.5 (B2), U3.2 (~RTS)
RXD: J3.3, U1.34 (RXD0/IO3), U3.20 (TXD)
SCL: J5.3, R17.2, U1.36 (IO22)
SDA: J5.4, R16.2, U1.33 (IO21)
TXD: J3.2, U1.35 (TXD0/IO1), U3.4 (RXD)

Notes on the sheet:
Fuse holder placeholders to get them in bom

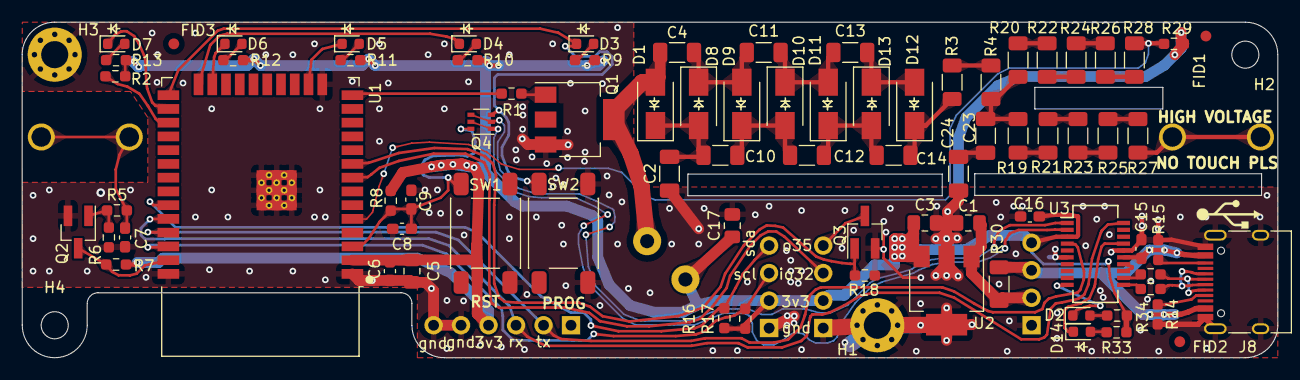
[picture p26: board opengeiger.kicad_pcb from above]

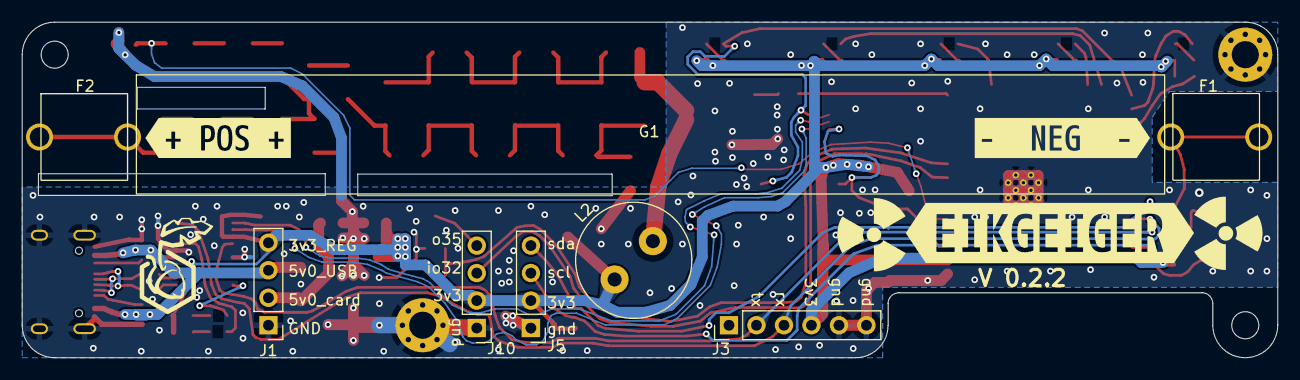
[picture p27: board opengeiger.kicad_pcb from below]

Board: 2 copper layers, 116.0 x 31.0 mm, 95 parts (11 on the bottom side), 62 nets.

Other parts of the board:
kibuzzard-637F3F6B: G***; kibuzzard-637F3F6B
kibuzzard-6571CD20: G***; kibuzzard-6571CD20
kibuzzard-6571CD43: G***; kibuzzard-6571CD43

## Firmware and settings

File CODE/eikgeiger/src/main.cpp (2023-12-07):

#include <Arduino.h>
#include <DNSServer.h>
#include <WiFi.h>
#include <HTTPClient.h>
#include <AsyncTCP.h>
#include "ESPAsyncWebServer.h"
#include <EEPROM.h>

#define EEPROM_SIZE 1024
#define BUF_VOLT 100
#define BUF_VOLT_LONG 200
#define BUF_CLICK 60
#define BUF_CLICK_HOUR 60
#define LED_0 0 
#define LED_1 2
#define LED_2 13
#define LED_3 15
#define LED_4 4
#define BUCK_PIN 12
#define BOOTBUTTON 12
#define CLICKER_PWM_CHANNEL 11
#define BUCK_PWM_CHANNEL 0
#define CLICKER 33 //Speaker element
#define REF_PIN 39 //ADC Input
#define PULSEPIN 23 //Geiger pulse input
#define SERVER_IP       "192.168.0.30"
#define AP_IP           "10.0.10.1"
#define NTP_SERVER      "no.pool.ntp.org"
#define LOG_PORT        8080
#define DEVICE_HOSTNAME "EIKGEIGER-WIFI" 


const char *HELP ="|----------------------------------------------------------------|\n"
                  "|   Characters  |   Unit                  |   Value   | DEFAULT  |\n"
                  "|---------------|-------------------------|-----------|----------|\n"
                  "| VO            |  VOLT (value/4096 %)    | 0-2000    | 400      |\n"
                  "| VF            |  FREQUENCY (hz)         | 0-18000   | 1001     |\n"
                  "| SA            |  SAVE TO EPPROM         | 1         | -        |\n"
                  "| RE            |  REBOOT SYSTEM          | 1         | -        |\n"
                  "| RF            |  FACTORYRESET(FULL/PART)| 9999/1111 | -        |\n"
                  "| BE            |  BEEPER (activation)    | 0/1       | 0        |\n"
                  "| BD            |  BEEPER duty (val/255)  | 0-127     | 50       |\n"
                  "| BF            |  BEEPER FREQUENCY (hz)  | 10-40000  | 6000     |\n"
                  "| LE            |  LED (activation)       | 0/1       | 1        |\n"
                  "| LF            |  FLASHTIME (mS)         | 1-500     | 10       |\n"
                  "| LO            |  LOG OUTPUT(Activation) | 0/1       | 1        |\n"
                  "| LS            |  LOG SPEED (ms/log)     | 0-10000   | 1000     |\n"
                  "| EV            |  EVENTSPERCLICK (number)| 0-1000    | 0        |\n"
                  "|----------------------------------------------------------------|\n";


// Helper menu to explain the different values
const char *EXPLAIN ="|--------------------------------------------------------------------------|\n"
                     "|   Variabel  |   Explaination                                             |\n"
                     "|-------------|------------------------------------------------------------|\n"
                     "| raw_volt    |integer between 0 and 2048, mapped to voltage range 0-1300  |\n"
                     "| set_volt    |integer between 0 and 2048. Duty cycle                      |\n"
                     "| cpmM        |floating average 60 seconds clicks per min                  |\n"
                     "| cpmH        |floating average clicks per min over an hour                |\n"
                     "| cpm         |cpm calculated from number of ms since last click           |\n"
                     "|--------------------------------------------------------------------------|\n";

int   buf_volt[BUF_VOLT]   = {0};
int   buf_volt_index       = 0;
float buf_volt_avg         = 0.0;

unsigned long buf_click[BUF_CLICK]  = {0};
int           buf_click_index       =  0;
float         buf_click_avg         =  0.0;

unsigned long buf_click_hour[BUF_CLICK]  = {0};
int           buf_click_hour_index       =  0;
float         buf_click_hour_avg         =  0.0;
float cpm = 0;


volatile unsigned long clicks = 0;
volatile unsigned long click_old=0;
volatile unsigned long ticks = micros();
volatile unsigned long ticks_old = ticks-10;
volatile unsigned long ticks_dt = 0;

unsigned long previousMillis_wifi = 0;
int interval_wifi = 30000;

unsigned long duration = millis();

unsigned long first = millis();
unsigned long last = first+1;
unsigned long now = last+1;

unsigned long last_2 = now+1;
unsigned long now_2 = last_2+1;

int num_radmon_fails = 0;

//server
int statusCode;
const char* ssid = "Default SSID";
const char* passphrase = "Default passord";
String st;
String content;
String esid;
String epass = "";

DNSServer dnsServer;
AsyncWebServer server(80);

bool wifi_conn = false;

typedef struct {
  //HV PWM DUTY CYCLE config_data.BUCK_PWM_SETPOINT/4095
  uint BUCK_PWM_SETPOINT=400;
  //PWM Frequency
  uint BUCK_PWM_FREQ = 1001;
  //CLICK SOUND ONOFF
  bool CLICKER_ACTIVATE = false;
  //Duty cycle for clicker config_data.CLICKER_DUTYCYCLE/255
  uint CLICKER_DUTYCYCLE = 50;
  //CLICKER PWM FREQUENCY
  uint CLICKER_FREQ = 6000;
  //Activate click indication leds
  bool LED_ACTIVATE = true;
  //How long to flash and click
  uint INDICATION_LENGTH = 10;
  //LOG OUTPUT onoff
  bool LOG_OUTPUT = true;
  //LOG OUTPUT WAITTIME
  uint LOG_SPEED = 1000;
  //Number of events per indication
  uint EVENT_DELAY = 0;
  //MCU-chip-UID
  char ssid[23]={};
  //Stored ssid name up to 128 chars
  char WIFI_SSID[128]={};
  //Stored password up to 128 chars
  char WIFI_PASS[128]={};
  //Stored IP
  byte ip[4] ={0,0,0,0};
  //radmon_username
  char RADMON_USER[128]={};
  //Stored password up to 128 chars
  char RADMON_PASS[128]={};
  //NTP Server
  char server_ip[30] = SERVER_IP;
  char ap_ip[30]     = AP_IP;
  char ntp_server[40] = NTP_SERVER;
  int  log_port= LOG_PORT;
  char device_hostname[64] = DEVICE_HOSTNAME;
} Configuration;

Configuration config_data;
Configuration config_data_bcp;

void loadConfig(Configuration& config) {
  EEPROM.get(0, config);
}

void saveConfig(Configuration& config) {
  EEPROM.put(0, config);
  EEPROM.commit();
}

void eepromCheck(){
  
  char ssid[23];
  snprintf(ssid, 23, "MCUDEVICE-%llX", ESP.getEfuseMac());
  Serial.print("ID: ");
  Serial.println(ssid);
  Serial.print("Mac Address: ");
  Serial.println(WiFi.macAddress());
  loadConfig(config_data);
  strcpy(config_data_bcp.ssid,ssid);

  if( strcmp(config_data.ssid, config_data_bcp.ssid) == 0){
    Serial.println("Loaded eeprom config successfully");
  }
  else{
    saveConfig(config_data_bcp);
    Serial.println("No eeprom config detected, initialized new config");
  }
}

void erase_eeprom(){
  for (int i = 0; i < EEPROM_SIZE; i++) {
    EEPROM.write(i, 0);
  }
  EEPROM.commit();
  delay(500);
}

void IRAM_ATTR ISR() {
  ticks_old = ticks;
  ticks = micros();
  clicks++;
  ticks_dt = ticks-ticks_old;
}

volatile unsigned long reset_clicks = 0;
volatile unsigned long reset_ticks_old = 0;
volatile unsigned long reset_ticks = micros();

void IRAM_ATTR RESET_INT() {

  reset_clicks++;
  reset_ticks = millis();
  if(reset_ticks_old-reset_ticks > 2000){
    reset_clicks = 0;
  }

  if(reset_clicks > 5){
    erase_eeprom();
    saveConfig(config_data_bcp);
    esp_restart();
  }
}

float array_calculate_avg(int * buf, int len){
      int sum = 0;

      for (int i = 0; i < len; i++)
      {
          sum += buf[i];
      }

      return ((float) sum) / ((float) len);
}


float array_minmax_avg(unsigned long * buf, int len){
      unsigned long maxVal = buf[0];
      unsigned long minVal = buf[0];

      for (int i = 0; i < len; i++)
      {
        if (buf[i] > maxVal) {
          maxVal = buf[i];
              }
        if (buf[i] < minVal) {
          minVal = buf[i];
        }
      }

      return ((float) (maxVal-minVal));
}

float adc2volt(unsigned int adc){
  float volt = map(adc, 0, 2047, 150, 2450);
  volt = volt / 1000.;
  return volt;
}

float voltdivider(float volt, int r1, int r2){
  return volt*float((r1+r2)/r2);
}

int revsetpoint(float volt){
  float r1 = 50000.;
  float r2 = 100.;
  volt = 1000*volt/float((r1+r2)/r2);
  int adc = map(volt, 150, 2450, 0, 2047);
  return adc;
}

void printbuf(unsigned int *buf, int len){
    for (int i = 0; i < len; i++){
        Serial.print(buf[i]);
        Serial.print("\t");
    }
    Serial.println();
}

void scanwifi(){
  WiFi.mode(WIFI_STA);
  WiFi.disconnect();
  delay(100);
  int n = WiFi.scanNetworks();
  Serial.println("scan done");
  if (n == 0)
    Serial.println("no networks found");
  else
  {
    Serial.print(n);
    Serial.println(" networks found");
    for (int i = 0; i < n; ++i)
    {
      // Print SSID and RSSI for each network found
      Serial.print(i + 1);
      Serial.print("\t(");
      Serial.print(WiFi.RSSI(i));
      Serial.print(")");
      Serial.print("\t");
      Serial.print(WiFi.SSID(i));
      Serial.println();
    }
  }
  Serial.println();
  st = "<ol>";
  for (int i = 0; i < n; ++i)
  {
    // Print SSID and RSSI for each network found
    st += "<li>";
    st += WiFi.SSID(i);
    st += "\t(";
    st += WiFi.RSSI(i);
    st += ")";
    //st += (WiFi.encryptionType(i) == ENC_TYPE_NONE) ? " " : "*";
    st += "</li>";
  }
  st += "</ol>";
}

class CaptiveRequestHandler : public AsyncWebHandler {
public:
  CaptiveRequestHandler() {}
  virtual ~CaptiveRequestHandler() {}

  bool canHandle(AsyncWebServerRequest *request){
    //request->addInterestingHeader("ANY");
    return true;
  }

  void handleRequest(AsyncWebServerRequest *request) {
    AsyncResponseStream *response = request->beginResponseStream("text/html");
    response->print("<!DOCTYPE html><html><head><title>EIKGEIGER CONFIG</title></head><body>");
    response->print( "<h1>EIKGEIGER CONFIG</h1>");
    response->printf("<p>The geiger counter is active, it is configured for %i /4096 duty cycle</p>",config_data.BUCK_PWM_SETPOINT);
    response->print( "<p>To change voltage or params use a serial monitor and connect with  115200 baud.</p>");
    response->print( "<p>Send 'H' over serial to get a help menu<br><br></p>");
    response->printf("<p>Average CPM last minute is  %.2f clicks per minute</p>", array_minmax_avg(buf_click, BUF_CLICK));
    response->print( "<p>Please write which wifi you want to connect and radmon credentials</p>");
    response->printf("<p>Try opening <a href='http://%s'>this link</a> to get ip page</p>", WiFi.softAPIP().toString().c_str());
    response->print( st );
    response->printf( "<form action='./post' method='POST'>"
                  "<p><label for='ssid'>SSID, write name for found wifi</label><br>"
                  "<input type='text' id ='ssid' name='ssid' value='%s'><br><br>",config_data.WIFI_SSID);

    response->print("<label for='pass'>WIFI Password </label><br>"
                      "<input type='text' id ='pass' name='pass'><br><br>");

    response->printf("<label for='radmon_username'>Radmon_username, register user at <a href='https://radmon.org/index.php/register'>Radmon.org</a></label><br>"
                      "<input type='text' id ='radmon_username' name='radmon_username' value='%s'><br><br>",config_data.RADMON_USER);
                    
    response->printf("<label for='radmon_pass'>Radmon device password (NOT login password)</a></label><br>"
                      "<input type='text' id ='radmon_pass' name='radmon_pass' value='%s'><br><br>",config_data.RADMON_PASS);

    response->print(  "<input type ='submit' value ='Submit'></p></form>" );
    response->print( "</body></html>");
    request->send(response);
  }
};


void start_main_page(){
  server.on("/", HTTP_GET, [](AsyncWebServerRequest * request) {
  AsyncResponseStream *response = request->beginResponseStream("text/html");
  response->print("<!DOCTYPE html><html><head><title>EIKGEIGER CONFIG</title></head><body>");
  response->print( "<h1>EIKGEIGER CONFIG</h1>");
  response->printf("<p>The geiger counter is active, it is configured for %i /4096 duty cycle</p>",config_data.BUCK_PWM_SETPOINT);
  response->print( "<p>To change voltage or params use a serial monitor and connect with  115200 baud.</p>");
  response->print( "<p>Send 'H' over serial to get a help menu<br><br></p>");
  response->printf("<p>Average CPM last minute is  %.2f clicks per minute</p>", array_minmax_avg(buf_click, BUF_CLICK));
  response->print( "<p>Please write which wifi you want to connect and radmon credentials</p>");
  response->printf("<p>Try opening <a href='http://%s/cpm'>this link</a> to get API page</p>", WiFi.localIP().toString().c_str());
  response->printf( "<form action='./post' method='POST'>"
                    "<p><label for='ssid'>SSID, write name for found wifi</label><br>"
                    "<input type='text' id ='ssid' name='ssid' value='%s'><br><br>",config_data.WIFI_SSID);

  response->printf("<label for='pass'>WIFI Password </label><br>"
                    "<input type='text' id ='pass' name='pass'value='%s'><br><br>",config_data.WIFI_PASS);

  response->printf("<label for='radmon_username'>Radmon_username, register user at <a href='https://radmon.org/index.php/register'>Radmon.org</a></label><br>"
                    "<input type='text' id ='radmon_username' name='radmon_username' value='%s'><br><br>",config_data.RADMON_USER);
                  
  response->printf("<label for='radmon_pass'>Radmon device password (NOT login password)</a></label><br>"
                    "<input type='text' id ='radmon_pass' name='radmon_pass' value='%s'><br><br>",config_data.RADMON_PASS);

  response->print(  "<input type ='submit' value ='Submit'></p></form>" );
  response->print( "</body></html>");
  request->send(response);
  });
}

void start_response_server(){
  server.on("/post", HTTP_POST, [](AsyncWebServerRequest * request) 
  {
    int paramsNr = request->params(); // number of params (e.g., 1)
    /*
    0 Param name: ssid                Value: testssid
    1 Param name: pass                Value: testpassord
    2 Param name: ip                  Value: 1.2.3.4
    3 Param name: gateway             Value: 255.255.255.255
    4 Param name: radmon_username     Value: testrad
    5 Param name: radmon_pass         Value: testradpass
    */
    //SSID
    AsyncWebParameter * r = request->getParam(0); // 1st parameter
    String string_val = r->value();
    char data[128] = {};
    strcpy(data,string_val.c_str());
    if (strlen(data) != 0){
      strcpy(config_data.WIFI_SSID,data);
    }
    //SSID_pass
    r = request->getParam(1); // 1st parameter
    string_val = r->value();
    data[0] = '\0';
    strcpy(data,string_val.c_str());
    strcpy(config_data.WIFI_PASS,data);
    
    //RADMON_USER
    r = request->getParam(2); // 1st parameter
    string_val = r->value();
    data[0] = '\0';
    strcpy(data,string_val.c_str());
    strcpy(config_data.RADMON_USER,data);
    
    //RADMON_USER_PASS
    r = request->getParam(3); // 1st parameter
    string_val = r->value();
    data[0] = '\0';
    strcpy(data,string_val.c_str());
    strcpy(config_data.RADMON_PASS,data);

    request->send(200);

    saveConfig(config_data);
    esp_restart();
  });

  server.on("/cpm", HTTP_GET, [](AsyncWebServerRequest * request) 
  {
     AsyncResponseStream *response = request->beginResponseStream("text/html");
    response->printf("{\"data\":{\"cpm\":%.3f,\"cpm_M\":%.2f,\"cpm_H\":%.2f,\"raw_volt\":%i}}",
                      float(60/float(ticks_dt/1e6)),
                      array_minmax_avg(buf_click, BUF_CLICK),
                      array_minmax_avg(buf_click_hour, BUF_CLICK)/60.,
                      analogRead(REF_PIN)
    );

    request->send(response);
  });
}

void ap_init(){
  scanwifi();
  WiFi.softAP("EIKGEIGER-captive");
  start_response_server();
  dnsServer.start(53, "*", WiFi.softAPIP());
  server.addHandler(new CaptiveRequestHandler()).setFilter(ON_AP_FILTER);//only when requested from AP
  //more handlers...
  IPAddress myIP = WiFi.softAPIP();
  Serial.print("AP IP address: ");
  Serial.println(myIP);
  server.begin();
}
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
void loop() {
  unsigned long start = micros();
  
  //Clicker logic
  clicker_logic();

  //Serial Output
  serial_handler();

  //COUNTER LOOP
  counter_loop();
  
  //SERIAL LOOP
  log_loop();

  //Server Handler
  if ( wifi_conn == false){
    dnsServer.processNextRequest();
  }
  else{
    check_and_reconnect();
  }
}

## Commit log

2022-11-03 Feat: First repo push, JLC prod
    [CUI_DEVICES_TB010-508-02BE.step, USB4105-15-A-120.stp, opengeiger.kicad_pcb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]
2022-11-03 Feat: Added 3d models and did a new export
    [opengeiger.kicad_pcb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]
2022-11-03 Feat:Added schematics, and updated readme
    [opengeiger.kicad_sch]
2022-11-03 Feat: Added schematic link in readme
2022-11-21 feat: added interactive html bom
    [opengeiger.kicad_pcb, opengeiger.kicad_sch]
2022-11-21 feat: 1206 version
    [opengeiger.kicad_pcb, opengeiger.kicad_sch]
2022-11-22 Feat: Slimmify board
    [opengeiger.kicad_pcb, opengeiger.kicad_sch]
2022-11-23 Feat: Slimmify more and usb uart
    [opengeiger.kicad_pcb, opengeiger.kicad_sch]
2022-11-24 Feat:WIP Rounding tracks
    [opengeiger.kicad_pcb, opengeiger.kicad_sch]
2022-11-24 Feat:Round Corners, temp gerber production
    [opengeiger-rounded.kicad_pcb, opengeiger.kicad_pcb, opengeiger_ROUND.kicad_pcb]
2022-11-25 Feat: Production files for JLC prod, readme update
    [opengeiger-rounded.kicad_pcb, opengeiger.kicad_pcb, opengeiger.kicad_sch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]
2022-11-25 Feat: html bom and added prod csv files
    [bom.csv, designators.csv, positions.csv]
2022-11-30 Feat:Code folder and charge pump simulation
2022-12-07 FEAT:PID reg wip
2022-12-08 Feat: PWM pid
2022-12-09 Feat: New prod, working code
    [bom.csv, opengeiger-rounded.kicad_pcb, opengeiger.kicad_pcb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]
2022-12-09 Feat: Fixed adc port and captive portal
    [opengeiger.kicad_pcb, opengeiger.kicad_sch]
2022-12-10 Feat: Got rid of pid
2022-12-11 Feat: New order from jlcpcb rev 0.2.1
    [bom.csv, designators.csv, opengeiger-rounded.kicad_pcb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]
2022-12-11 Feat:Updated schematic revnr and pdfprint and pict
    [opengeiger.kicad_sch]
2022-12-12 Feat: Readme and licensing
    [BODY.stl, Enclosure v4.f3z, LID.stl]
2022-12-12 Fix: Case link
2022-12-15 Feat: Added help menu, fixed readme error
    [main.cpp]
2022-12-30 Fix: Formatted JSON output
    [main.cpp]
2022-12-30 Fix: Removed two unused text inputs in ap
    [main.cpp]
2023-01-23 Fix: Small additions to "?" merger
    [main.cpp]
2023-12-01 Feat:Printing macaddress
2023-12-04 Feat: Added LCSC part numbers to schematics
    [bom.csv, designators.csv, opengeiger.kicad_pcb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]
2023-12-06 Feat: New 3d models
    [Enclosure_SBM19 v15.3mf, Enclosure_SBM20 v3.3mf]
2023-12-07 Feat: Update to 0.2.2
    [bom.csv, designators.csv, opengeiger-rounded.kicad_pcb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]
2023-12-07 Feat: Cleanup in enclosures
    [BODY.stl, Enclosure v4.f3z, LID.stl]
2023-12-07 Feat: Fixed wrong pin assignment for beeper
    [main.cpp]
2024-01-11 Schematic prettify

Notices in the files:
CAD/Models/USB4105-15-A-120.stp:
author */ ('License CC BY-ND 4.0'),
